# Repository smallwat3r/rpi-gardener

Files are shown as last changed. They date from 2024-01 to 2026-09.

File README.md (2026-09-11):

# RPi Gardener

Monitor your plant environment with a Raspberry Pi 4 and Raspberry Pi Pico.

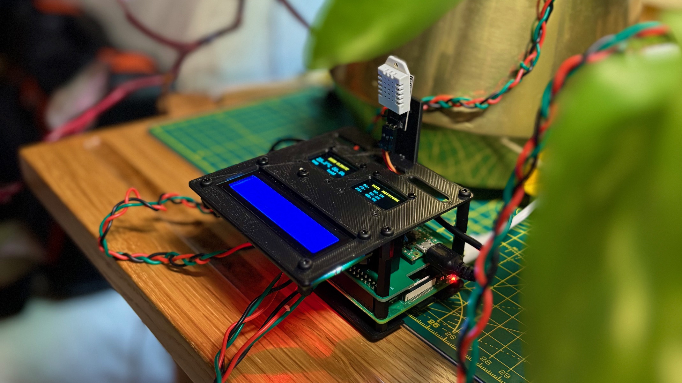
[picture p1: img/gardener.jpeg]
gardener


Tracks temperature, humidity, and soil moisture with a real-time web dashboard, displays, smart alerts, and more.

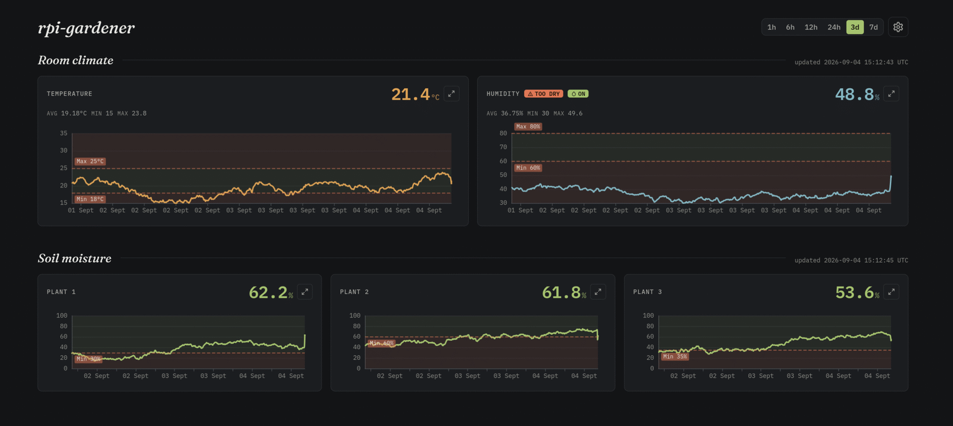
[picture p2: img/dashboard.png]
dashboard


## Features

- Real-time temperature and humidity monitoring (DHT22)
- Soil moisture tracking for up to 3 plants (Pico + capacitive sensors)
- Modern web dashboard with live charts and threshold visualization
- Visual alerts when sensor values exceed configured thresholds
- Password-protected admin interface to manage settings
- 128x64 OLED displays on both RPi and Pico
- 16x2 LCD alert display with scrolling text
- Notifications when thresholds are crossed and when alerts resolve
- Smart plug automation (TP-Link Kasa) for humidity control
- Custom RPi HAT PCB and 3D-printable case (optional, can also wire manually)
- Docker deployment

## Requirements

- Raspberry Pi 4 with Docker installed
- Raspberry Pi Pico (connected via USB for soil moisture sensors)
- DHT22 temperature/humidity sensor
- 2x SSD1306 OLED displays (128x64) - one for Pico, one optional for RPi
- 3x capacitive soil moisture sensors (v1.2)
- 1602A LCD with I2C backpack (optional, for alert display)
- TP-Link Kasa smart plug (optional, for automatic humidity control)

### Why both a Pico and a Raspberry Pi?

The Raspberry Pi 4 doesn't have analog-to-digital converter (ADC) inputs,
which are required to read capacitive soil moisture sensors. A common solution
is to add an external ADC module (like the ADS1115) to the RPi's I2C bus.
However, this project uses a Raspberry Pi Pico instead for several reasons:

- **Practical**: I already had a Pico lying around, so why not put it to use
- **More GPIO**: The Pico provides 3 ADC pins and 26 GPIO pins total, leaving
  plenty of room for additional sensors or peripherals without competing for
  the RPi's limited GPIO. Future additions like light sensors, water level
  sensors, or relay controls can be handled entirely by the Pico
- **Architectural separation**: Keeping sensor reading on a dedicated
  microcontroller isolates it from the main application. The Pico handles
  real-time ADC sampling and display updates, while the RPi focuses on the web
  server, database, and notifications. If the RPi application crashes or
  restarts, the Pico keeps running independently
- **Network scalability**: Using a Pico W instead of the standard Pico allows
  sensors to communicate over WiFi rather than USB serial. This enables a
  distributed setup where multiple Picos in different locations (greenhouse,
  garden beds, indoor plants) can all report back to a single RPi base station
  over the network

## Quick Start

### Deploy from your machine

First create a `.env` in this checkout, see [Configure Environment](#3-configure-environment)
for the values:

    cp .env.example .env

Then, with SSH access to the Pi (Raspberry Pi OS, a user with sudo), one
command provisions the host, syncs the code and starts the stack:

    make deploy DEPLOY_HOST=pi@gardener.local

`DEPLOY_HOST` is anything `ssh` accepts, `user@host`, an IP, or an alias from
your SSH config.

Provisioning is idempotent and covers: I2C, a 50MB journald cap and swap off
(both to limit SD card wear), Docker via get.docker.com, the docker group,
and the monthly Tailscale cert renewal cron. Your `.env` is copied to the Pi
on the first deploy only, later edits are made on the Pi. Re-run
`make deploy` to ship code changes.

The manual steps below are what `make deploy` does, for reference.

### 1. Prepare the Raspberry Pi

Enable I2C:

    sudo raspi-config  # Interface Options -> I2C -> Enable
    sudo modprobe i2c-dev
    echo "i2c-dev" | sudo tee -a /etc/modules

Cap the system journal so it cannot wear the SD card (container logs are
already capped in `docker-compose.yml`):

    sudo mkdir -p /etc/systemd/journald.conf.d
    printf '[Journal]\nSystemMaxUse=50M\n' | sudo tee /etc/systemd/journald.conf.d/sdcard.conf
    sudo systemctl restart systemd-journald

### 2. Install Docker

    curl -fsSL https://get.docker.com | sudo sh
    sudo usermod -aG docker $USER
    sudo reboot  # reboot pi

### 3. Configure Environment

Create a `.env` file:

```sh
# SSL certificate (use your RPi's local IP)
CERT_IP=192.168.1.100

# Admin password for the settings UI (optional, off by default)
# When set, the settings UI asks for username "admin" and this password
ADMIN_PASSWORD=your_secure_password

# DHT22 thresholds (optional, these are defaults)
MAX_TEMPERATURE=25
MIN_TEMPERATURE=18
MAX_HUMIDITY=65
MIN_HUMIDITY=40

# Moisture thresholds (optional)
# Default for all plants
MIN_MOISTURE=30
MIN_MOISTURE_PLANT_1=25
MIN_MOISTURE_PLANT_2=30
MIN_MOISTURE_PLANT_3=35

# Notifications (optional, set to 1 to enable)
ENABLE_NOTIFICATION_SERVICE=0
# Backends: "gmail", "slack", or "gmail,slack" for both
NOTIFICATION_BACKENDS=gmail

# Gmail
GMAIL_SENDER=
GMAIL_RECIPIENTS=
GMAIL_USERNAME=
GMAIL_PASSWORD=

# Slack (create webhook at https://api.slack.com/messaging/webhooks)
SLACK_WEBHOOK_URL=

# Humidifier (optional, TP-Link Kasa smart plug)
# Automatically controls a humidifier based on humidity alerts
ENABLE_HUMIDIFIER=0
HUMIDIFIER_HOST=192.168.1.100  # IP address of your Kasa plug

# OLED display (optional, SSD1306 128x64)
# Shows temperature and humidity readings
ENABLE_OLED=0

# LCD 1602A alert display (optional)
# Shows active alerts with scrolling text
ENABLE_LCD=0
LCD_I2C_ADDRESS=0x27           # Use 0x3F if 0x27 doesn't work
LCD_SCROLL_DELAY_SEC=0.7       # Scroll speed (lower = faster)
```

### 4. Start Services

    make up

The dashboard will be available at `https://YOUR-RPI-IP/`

(Accept the self-signed certificate warning in your browser)

### 5. Set Up the Pico

See [pico/README.md](./pico/README.md) for Pico installation instructions.

## Commands

### Production (Raspberry Pi)

```bash
make up          # Start all services
make up-rebuild  # Rebuild (clears static volume for fresh FE)
make down        # Stop services
make logs        # View all logs
make logs-app    # View app container logs
make restart     # Restart services
make clean       # Stop and remove volumes
make mprestart   # Restart Pico script (if it loses sync)
```

### Development (local machine)

Run the dashboard locally without RPi hardware. The dev environment uses mock
sensors (`MOCK_SENSORS=1`) to generate realistic data without physical hardware.

```bash
cp .env.example .env   # Configure environment
make dev               # Start dev environment
make dev-seed          # Seed database with sample data
make dev-logs          # View logs
make dev-down          # Stop dev environment
make dev-rebuild       # Rebuild after frontend changes
```

The dev dashboard will be available at `http://localhost:5000/`

### Testing

```bash
make devdeps     # Install dev dependencies
make test        # Run test suite
make lint        # Run linters
```

## Pico Communication

The Pico sends moisture readings via USB serial as JSON, including raw ADC values for debugging:

    {"plant-1": {"pct": 45.2, "raw": 29550}, "plant-2": {"pct": 67.8, "raw": 25000}, ...}

The RPi auto-detects `/dev/ttyACM0` or `/dev/ttyACM1` and persists readings directly to the database.

## Data Management

- Historical data is automatically deleted after the configured retention period (default: 7 days)
- Retention period can be changed via the admin interface
- Database persisted in Docker volume `rpi-gardener-db`
- Regenerate SSL certs by removing volume: `docker volume rm rpi-gardener-certs`

## Troubleshooting

See [TROUBLESHOOTING.md](./TROUBLESHOOTING.md) for common issues and solutions.

## Security

This project is designed for local home networks:
- HTTPS with self-signed certificates
- Dashboard is publicly accessible (read-only)
- Settings UI is open by default, set `ADMIN_PASSWORD` to protect it with HTTP Basic Auth
- Do not expose to the internet without additional security

## Remote access with Tailscale (optional)

To reach the dashboard from outside your home network with a trusted (non
self-signed) certificate, put the Pi on a [Tailscale](https://tailscale.com)
tailnet and let nginx serve a Tailscale-issued cert.

nginx picks the certificate by hostname (SNI): requests to your `*.ts.net`
name get the Tailscale cert, everything else (local IP, `gardener.local`)
keeps the self-signed cert. Nothing changes for users who don't use Tailscale.

Seed the cert once on the Pi host (Tailscale must be installed and up):

```sh
./docker/tailscale-cert-renew.sh
```

Tailscale certs expire after 90 days. `make deploy` schedules the script in
the root crontab to renew monthly, or add it yourself (`sudo crontab -e`):

```cron
0 4 1 * * /path/to/rpi-gardener/docker/tailscale-cert-renew.sh >> /var/log/ts-cert.log 2>&1
```

The script is a no-op if Tailscale isn't installed, so it's safe to leave
scheduled regardless. Certs live in the persistent `rpi-gardener-certs` volume,
so they survive deploys and are not regenerated on `make up`.

## Hardware Build

There are two ways to build the hardware: using a custom PCB with 3D-printed case, or manual wiring on a breadboard.

### Option 1: Custom PCB Hat + Case

A custom PCB that mounts as a Raspberry Pi HAT with an integrated Pico. Includes 3D-printable base and display plates.

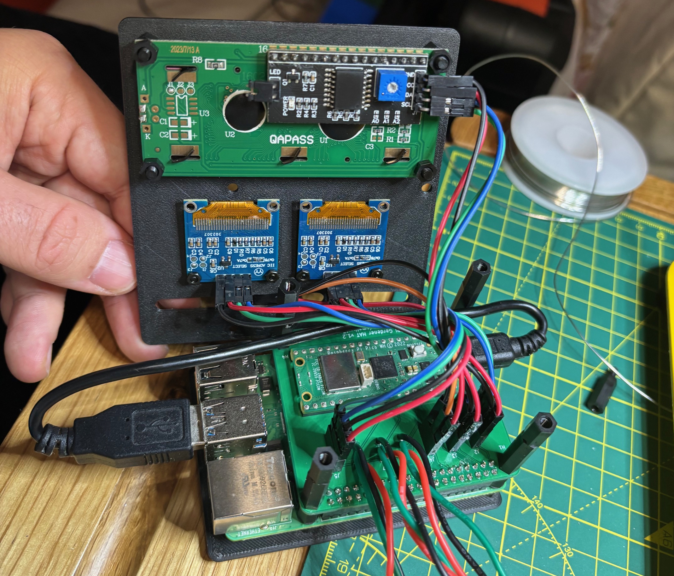
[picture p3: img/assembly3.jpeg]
pcb_with_case


See [hardware/README.md](./hardware/README.md) for:
- PCB specifications and manufacturing files
- 3D printable case files (OpenSCAD/STL)
- Complete bill of materials
- Step-by-step assembly instructions

### Option 2: Manual Wiring

For prototyping or if you prefer not to use the PCB. 

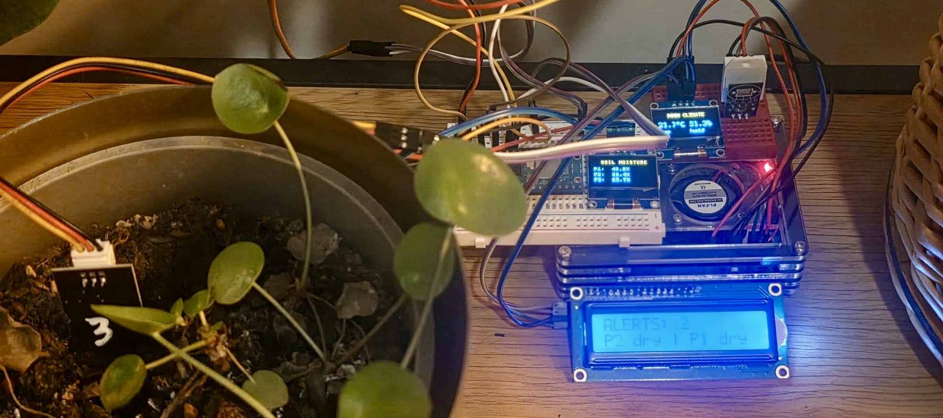
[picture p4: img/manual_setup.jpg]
manual_setup


Refer to [hardware/README.md](./hardware/README.md) for pin assignments and use the wiring diagram below as a reference.

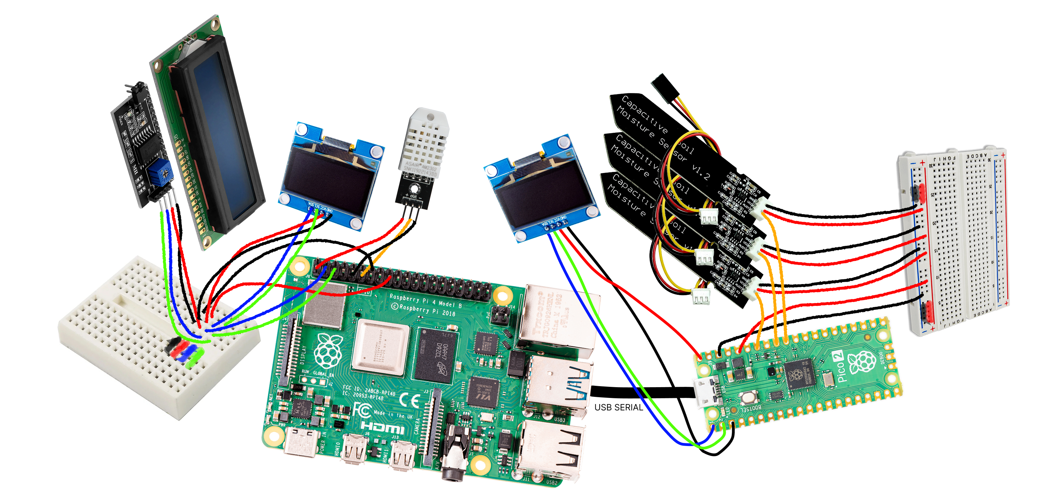
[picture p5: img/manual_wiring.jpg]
manual_wiring


## License

This project uses a dual-license structure:

- **Software** (code, scripts, configurations): [MIT License](./LICENSE)
- **Hardware** (`hardware/` directory): [CERN-OHL-P v2](./hardware/LICENSE)

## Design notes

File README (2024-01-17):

RPI DHT22 SERVER
----------------

This project contains necessarry files and scripts to read temperature and 
humidity data from a DHT22 sensor, wired to a Raspberry Pi 4. It stores the 
results every 2 seconds in a local Sqlite database, and renders them on a bare 
simple frontend using ChartJS powered by Flask and web-sockets.

REQUIREMENTS
------------

Get and build Python 3.12 from source

    sudo apt update
    sudo apt install build-essential zlib1g-dev libncurses5-dev libgdbm-dev \
        libnss3-dev libssl-dev libreadline-dev libffi-dev libsqlite3-dev
    wget https://python.org/ftp/python/3.12.1/Python-3.12.1.tgz
    tar -xf Python-3.12.1.tgz 
    cd Python-3.12.1
    ./configure --enable-optimizations
    sudo make altinstall

Create a Python virtual environment and install the Python dependencies 
(this is a one-off command)

    make venv deps
    
Install screen to run the commands in the background and keep them persistant

    sudo apt install screen

USAGE
-----

Run the dht sensor polling service
    
    make polling

From another terminal window, run the flask server
    
    make server

Run the commands in screen in order to keep them persistant over the SSH
session
   
    screen -d -m make polling
    screen -d -m make server

You can then list the running screen sessions with
   
    screen -ls

More screen commands see

    screen --help

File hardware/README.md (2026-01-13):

# RPi Gardener HAT

A custom PCB that combines a Raspberry Pi HAT with an integrated Raspberry Pi Pico for the RPi Gardener project.

## Contents

| Section | Description |
|---|---|
| [PCB](#pcb) | Board specifications, components, pinouts, manufacturing |
| [Case](#case) | 3D printable base and display plates |
| [Assembly](#assembly) | Hardware requirements, stack diagram, build steps |
| [Troubleshooting](#troubleshooting) | Common issues and solutions |

---

## PCB Hat

### Overview

This PCB serves as a unified interface board that:
- Mounts directly on a Raspberry Pi as a HAT (Hardware Attached on Top)
- Integrates a Raspberry Pi Pico for analog sensor readings
- Provides connectors for all sensors and displays

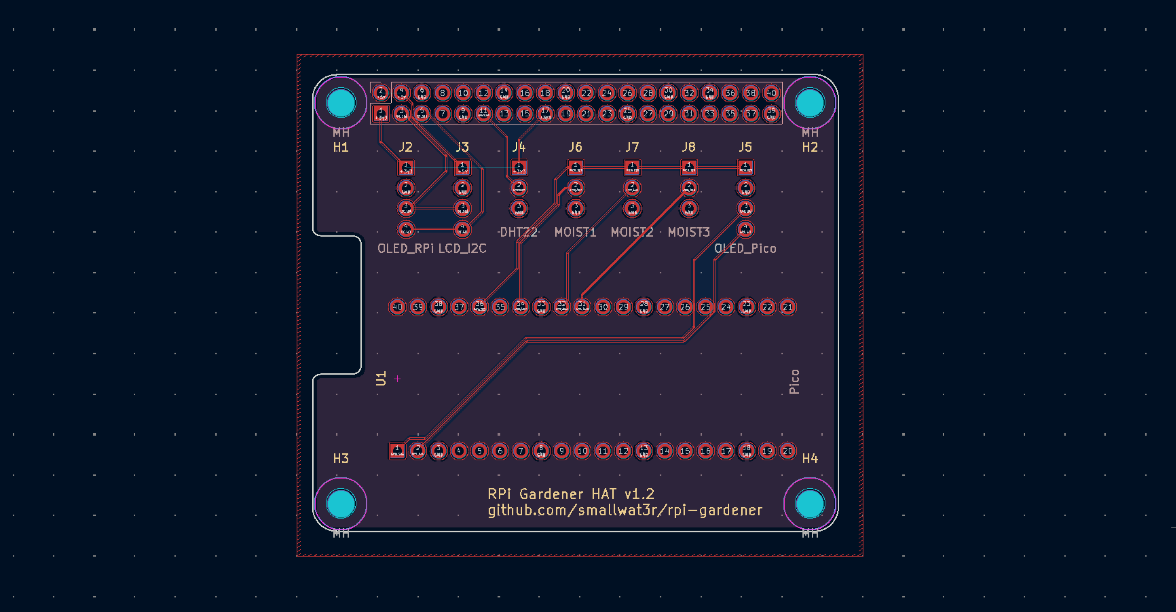
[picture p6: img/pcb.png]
pcb


### Board Specifications

| Property | Value |
|---|---|
| Dimensions | 65mm x 56mm (standard RPi HAT size) |
| Layers | 2 (F.Cu, B.Cu) |
| Thickness | 1.6mm |
| Mounting Holes | 4x M3 at standard HAT positions |
| Ground Planes | Both layers (unified GND net) |
| KiCad Version | 9.x |

### Components

#### Connectors

| Ref | Description | Pins | Connection |
|-----|---|---|---|
| J1 | RPi GPIO Header | 2x20 | Raspberry Pi 40-pin GPIO |
| J2 | OLED Display (RPi) | 1x4 | I2C SSD1306 128x64 |
| J3 | LCD Display | 1x4 | I2C 1602A with PCF8574 |
| J4 | DHT22 Sensor | 1x3 | Temperature/Humidity |
| J5 | OLED Display (Pico) | 1x4 | I2C SSD1306 128x64 |
| J6 | Moisture Sensor 1 | 1x3 | Capacitive soil sensor |
| J7 | Moisture Sensor 2 | 1x3 | Capacitive soil sensor |
| J8 | Moisture Sensor 3 | 1x3 | Capacitive soil sensor |

#### Modules

| Ref | Description | Footprint |
|-----|---|---|
| U1 | Raspberry Pi Pico | Through-hole (40 pins) |

#### Mounting

| Ref | Description |
|-----|---|
| H1-H4 | M3 mounting holes at standard HAT positions |

### Pin Assignments

#### Raspberry Pi GPIO (directly from J1)

| Function | GPIO | Pin |
|---|---|-----|
| I2C SDA | GPIO2 | 3 |
| I2C SCL | GPIO3 | 5 |
| DHT22 Data | GPIO17 | 11 |
| 3.3V Power | - | 1, 17 |
| 5V Power | - | 2, 4 |
| Ground | - | 6, 9, 14, 20, 25, 30, 34, 39 |

#### Raspberry Pi Pico (U1)

| Function | GPIO | Pin |
|---|---|-----|
| OLED SDA | GP0 | 1 |
| OLED SCL | GP1 | 2 |
| Moisture 1 | GP26/ADC0 | 31 |
| Moisture 2 | GP27/ADC1 | 32 |
| Moisture 3 | GP28/ADC2 | 34 |
| 3.3V Out | 3V3 | 36 |
| Ground | GND | 3, 8, 13, 18, 23, 28, 33, 38 |

### Connector Pinouts

#### J2 - OLED RPi (SSD1306 I2C)
```
Pin 1: VCC (3.3V)
Pin 2: GND
Pin 3: SDA (GPIO2)
Pin 4: SCL (GPIO3)
```

#### J3 - LCD I2C (1602A with PCF8574)
```
Pin 1: VCC (5V)
Pin 2: GND
Pin 3: SDA (GPIO2)
Pin 4: SCL (GPIO3)
```

#### J4 - DHT22 Sensor
```
Pin 1: VCC (3.3V)
Pin 2: DATA (GPIO17)
Pin 3: GND
```

#### J5 - OLED Pico (SSD1306 I2C)
```
Pin 1: VCC (Pico 3.3V)
Pin 2: GND
Pin 3: SDA (GP0)
Pin 4: SCL (GP1)
```

#### J6, J7, J8 - Moisture Sensors
```
Pin 1: VCC (Pico 3.3V)
Pin 2: SIG (GP26/GP27/GP28)
Pin 3: GND
```

### I2C Bus Configuration

The board has two separate I2C buses:

#### RPi I2C Bus (GPIO2/GPIO3)
- OLED Display (J2) - typically address 0x3C
- LCD Display (J3) - typically address 0x27 or 0x3F

#### Pico I2C Bus (GP0/GP1)
- OLED Display (J5) - typically address 0x3C

### USB Passthrough

The Pico's USB port is accessible at the board edge for:
- Serial communication with the Raspberry Pi
- Firmware updates
- Debugging

Connect using a USB-A to Micro-USB cable from any RPi USB port to the Pico.

### Files

| File | Description |
|---|---|
| `kicad/rpi-gardener-hat.kicad_pro` | KiCad project file |
| `kicad/rpi-gardener-hat.kicad_sch` | Schematic |
| `kicad/rpi-gardener-hat.kicad_pcb` | PCB layout |
| `kicad/rpi-gardener-hat.pretty/` | Custom footprint library |
| `kicad/gerber.zip` | Manufacturing files (Gerber + drill) |

### Manufacturing

Upload `kicad/gerber.zip` to your preferred PCB manufacturer (JLCPCB, PCBWay, etc.).

Recommended settings:
- Layers: 2
- Thickness: 1.6mm
- Surface finish: HASL (lead free) or ENIG
- Copper weight: 1oz
- Solder mask: Any color
- Silkscreen: White

Design rules used:
- Min track width: 0.2mm
- Min clearance: 0.2mm
- Min via diameter: 0.6mm
- Min via drill: 0.3mm

---

## Case

3D printable base and display plates for mounting the full assembly.

### Files

| File | Description |
|---|---|
| `case/rpi-gardener-base.scad` | OpenSCAD source for base plate |
| `case/rpi-gardener-base.stl` | Base plate STL |
| `case/rpi-gardener-display-plate.scad` | OpenSCAD source for display plate |
| `case/rpi-gardener-display-plate.stl` | Display plate STL |

### Base Plate

| Property | Value |
|---|---|
| Dimensions | 90mm x 62mm x 1.5mm |
| Mounting Pattern | 58mm x 49.5mm (matches RPi/HAT) |
| Hole Diameter | 3.2mm (M3 clearance) |
| Features | Ventilation slots, USB cable cutout |

### Display Plate

| Property | Value |
|---|---|
| Dimensions | 90mm x 100mm x 1.5mm |
| OLED Cutouts | 2x 26mm x 15mm (for 0.96" SSD1306) |
| OLED Mount Spacing | 23mm x 23.5mm (M2) |
| LCD Cutout | 73mm x 25mm (for 1602A) |
| LCD Mount Spacing | 75mm x 31mm (M3) |
| Features | Cable routing slots, DHT22 holder tab |

### Printing Settings

- Layer height: 0.2mm
- Infill: 20%
- Material: PLA or PETG
- Supports: Not required

### Regenerating STL

```bash
cd case
openscad -o rpi-gardener-base.stl rpi-gardener-base.scad
openscad -o rpi-gardener-display-plate.stl rpi-gardener-display-plate.scad
```

### Customization

Edit the `.scad` files to adjust dimensions, enable/disable features, or change OLED type (0.96" vs 1.3").

---

## Assembly

### Required Hardware

#### Stack Hardware

| Item | Quantity | Notes |
|---|---|---|
| M3 screws | 4 | Bottom, thread into F-M spacers |
| M3 screws | 4 | Top, thread into F-F spacers |
| M3 spacers (5-6mm, F-M) | 4 | Between base and RPi |
| M3 washers (1mm) | 4 | Between RPi and next spacer |
| M3 spacers (10mm, F-M) | 4 | Between RPi and HAT |
| M3 spacers (20mm, F-M) | 4 | Above HAT |
| M3 spacers (5-6mm, F-F) | 4 | Top, screws thread into these |
| Rubber bumpons (8-10mm) | 4 | Anti-slip feet under base plate |

#### Display Mounting

| Item | Quantity | Notes |
|---|---|---|
| M2 screws (1mm) | 8 | To attach OLEDs to display plate |
| M2 nuts | 8 | To secure OLEDs |
| M3 screws | 4 | To attach LCD to display plate |
| M3 spacers (5-6mm, F-M) | 4 | Between display plate and LCD |
| M3 nuts | 4 | To secure LCD |
| M3 screw | 1 | Front, to mount DHT22 to display plate pole |
| M3 spacer (F-M) | 1 | Between DHT22 and display plate pole |
| M3 nut | 1 | Back, to secure DHT22 |

#### PCB Components

| Item | Quantity | Notes |
|---|---|---|
| 2x16 pin male-to-female header | 2 | For J1 (RPi GPIO), allows RPi plug/unplug |
| 1x4 pin male-to-female header | 3 | For J2, J5 (OLEDs) and J3 (LCD) |
| 1x3 pin male-to-female header | 1 | For J4 (DHT22) |
| Pin headers for Pico | 2x20 | Or solder Pico directly |
| Capacitive soil sensors | 3 | Solder directly to J6, J7, J8 |
| Small dupont wires (M-F) | - | Modules have male pins, HAT has female headers |

**Note:** The RPi 4 has native M2.5 mounting holes. You may need to lightly drill or ream them to fit M3 screws.

### Stack Diagram

```
    ┌─────────────────────┐
    │   4x M3 screws      │  ← Thread into F-F spacers
    ├─────────────────────┤
    │   Display plate     │  ← Top plate with OLEDs + LCD
    ├─────────────────────┤
    │   4x spacers 5-6mm  │  ← F-F (top screws thread here)
    │ + 4x spacers 20mm   │  ← F-M
    ├─────────────────────┤
    │   HAT (PCB)         │  ← RPi Gardener HAT with Pico
    ├─────────────────────┤
    │   4x spacers 10mm   │  ← F-M
    ├─────────────────────┤
    │   4x washers 1mm    │  ← Fine adjustment
    ├─────────────────────┤
    │   Raspberry Pi      │  ← RPi 4
    ├─────────────────────┤
    │   4x spacers 5-6mm  │  ← F-M
    ├─────────────────────┤
    │   Base plate        │  ← 3D printed base
    ├─────────────────────┤
    │   4x M3 screws      │  ← Thread into F-M spacers
    └─────────────────────┘
```

### Assembly Steps

1. **Solder Components to HAT**
   - Solder 2x 16-pin male-to-female headers for J1 (RPi GPIO)
   - Solder 1x4 pin male-to-female headers for J2, J5 (OLEDs) and J3 (LCD)
   - Solder 1x3 pin male-to-female header for J4 (DHT22)
   - Solder capacitive soil sensors directly to J6, J7, J8 (see note below)
   - Mount Pico: solder directly or use pin headers

   **Note on soil sensor wiring:** From testing, soldering the sensors directly to the PCB produces much more reliable readings than joining multiple dupont cables, which can introduce noise and intermittent connections. An even better alternative is to use JST-XH connectors on both ends for a secure, detachable connection. You'll likely need long cables to reach plants around the installation.

2. **Mount Displays to Plate**
   - Attach OLEDs using 8x M2 screws (1mm) and 8x M2 nuts
   - Attach LCD using 4x M3 screws, 4x M3 spacers (5-6mm F-M), and 4x M3 nuts

3. **Build the Stack**
   - Insert 4x M3 screws from bottom through base plate into 4x 5-6mm F-M spacers
   - Place Raspberry Pi onto spacers
   - Add 4x 1mm washers
   - Add 4x 10mm F-M spacers
   - Mount HAT, seating GPIO connector onto RPi header
   - Add 4x 20mm F-M spacers
   - Add 4x 5-6mm F-F spacers

4. **Connect Peripherals**
   - Connect OLED displays to J2, J5 using dupont wires
   - Connect LCD 1602A to J3 using dupont wires
   - Connect DHT22 to J4 using dupont wires
   - Connect Pico USB to RPi USB port

5. **Secure Top Plate**
   - Place display plate on top
   - Secure with 4x M3 screws from top

6. **Mount DHT22 Sensor**
   - Attach DHT22 to display plate pole using M3 screw (front), M3 spacer F-M, and M3 nut (back)

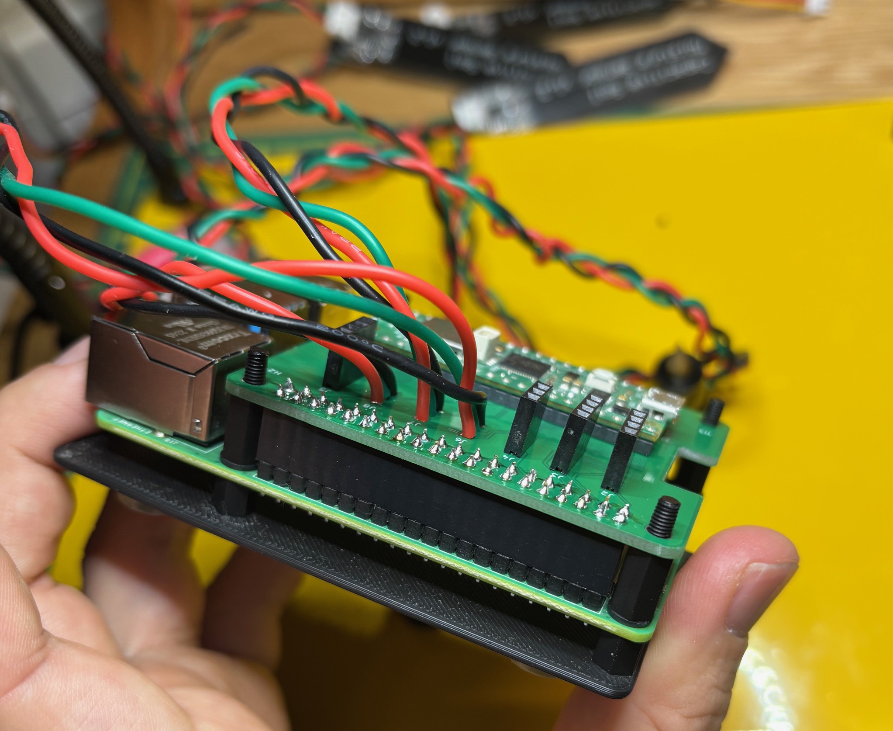
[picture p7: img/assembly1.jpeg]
assembly1

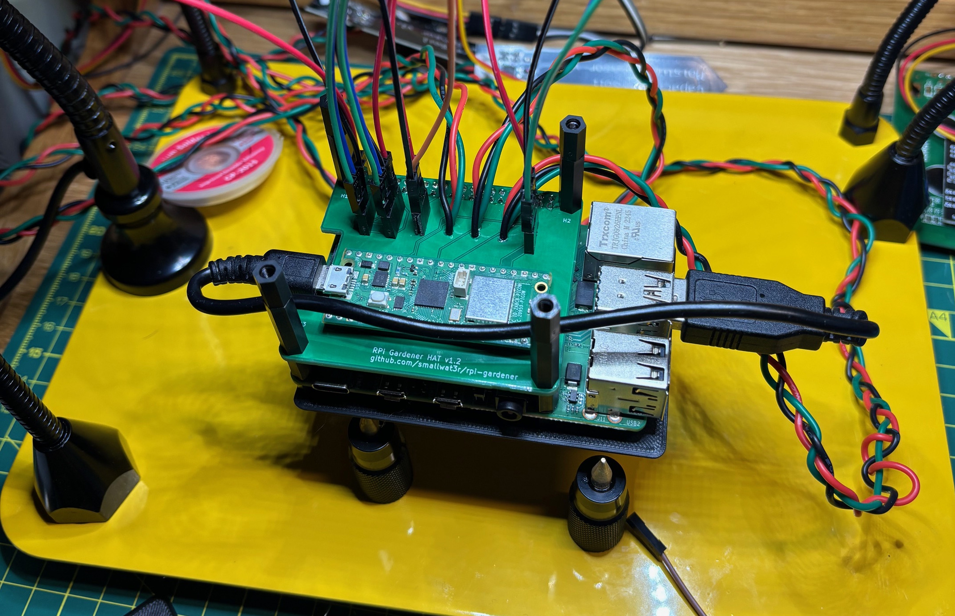
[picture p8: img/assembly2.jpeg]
assembly2

assembly3

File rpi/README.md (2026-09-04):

# RPi

Python code for the Raspberry Pi 4.

## Architecture

Services communicate via Redis pub/sub:

```
DHT Polling ──┐                  ┌── Web Server (SSE)
              │                  ├── Notification Service (Gmail/Slack)
              ├── Redis ─────────┼── Humidifier Service (Kasa smart plug)
Pico Reader ──┘                  ├── OLED Service (SSD1306 display)
                                 └── LCD Service (1602A alert display)
```

## Services

### DHT22 Polling Service (`dht/`)

Reads temperature and humidity from the DHT22 sensor every 2 seconds and
publishes every reading to the event bus. Only every 5th reading is stored,
batched into one database commit per minute, to limit SD card wear
(`PollingSettings.persist_every` and `flush_interval_sec`).

    make polling

### Pico Serial Reader (`pico/`)

Reads soil moisture data from a Pico microcontroller via USB serial.
Parses JSON lines and publishes readings to the event bus.

    make pico

### Web Server (`server/`)

REST API and SSE server for the dashboard. Uses Starlette (ASGI).
Subscribes to the event bus for real-time updates.

    make serve       # Development (with hot reload)
    make serve-prod  # Production (Unix socket for Nginx)

### Notification Service (`notifications/`)

Subscribes to alert events and sends notifications via Gmail/Slack.
Runs independently of the web server.

    python -m rpi.notifications

### Humidifier Service (`humidifier/`)

Controls a humidifier via TP-Link Kasa smart plug based on humidity alerts.
Turns on when humidity drops below the threshold,
and turns off when humidity recovers.

    python -m rpi.humidifier

### OLED Service (`oled/`)

Displays temperature and humidity readings on an SSD1306 OLED display (128x64).
Subscribes to DHT reading events and renders the latest values.

    python -m rpi.oled

Example display:
```
  ROOM CLIMATE
22.5°C    55.0%
temp      humid
```

### LCD Service (`lcd/`)

Displays active alerts on a 16x2 character LCD (1602A with I2C backpack).
Shows "All OK" when no alerts are active, or scrolling alert text when
thresholds are exceeded.

    python -m rpi.lcd

Example display:
```
ALERTS: 3
P1 dry | Temp low | Humid high
       ^^^^^^^^^^^^^^^^^^^^^^^^ (scrolling)
```

## Endpoints

| Endpoint | Method | Description |
|---|---|---|
| `/health` | GET | Service health check |
| `/api/dashboard` | GET | Dashboard data (JSON) |
| `/api/thresholds` | GET | Configured alert thresholds (JSON) |
| `/api/admin/settings` | GET | Admin settings (requires auth) |
| `/api/admin/settings` | PUT | Update admin settings (requires auth) |
| `/sse/dht/latest` | SSE | Real-time DHT22 readings |
| `/sse/pico/latest` | SSE | Real-time Pico readings |
| `/sse/humidifier/state` | SSE | Real-time humidifier state |

## Dashboard Features

The web dashboard displays:

- **Room Climate**: Temperature and humidity charts with min/max threshold lines
- **Soil Moisture**: Per-plant moisture charts with minimum threshold lines
- **Visual Alerts**: Warning badges appear when values exceed thresholds
  - Temperature: "Too hot" / "Too cold"
  - Humidity: "Too humid" / "Too dry"
  - Moisture: "Thirsty"
- **Danger Zones**: Red-shaded areas on charts indicate out-of-range values

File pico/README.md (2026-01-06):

# Pico

This module uses MicroPython and needs to be set up on the Raspberry Pico
board, to read values from capacitive soil moisture sensors (v1.2).

## Features

- Reads moisture levels from up to 3 capacitive soil sensors
- Sends readings to the RPi via USB serial (no WiFi required)
- Displays readings on an SSD1306 OLED display (128x64)

### OLED Display

The Pico shows soil moisture readings on a 128x64 SSD1306 OLED display
connected via I2C (GPIO 0/1). The display is optional - if not connected,
readings are still sent via USB serial.

Example display:
```
  SOIL MOISTURE
P1:  45.2%
P2:  67.8%
P3:  52.1%
```

## Installation

Connect the Pico to the RPi via USB cable.

From the RPi, install the MicroPython tooling:

    make mpdeps

### First-time setup

1. Install MicroPython on the Pico if not already done:
   - Hold BOOTSEL button while plugging in USB
   - Download the `.uf2` file from https://micropython.org/download/RPI_PICO/
   - Copy it to the mounted drive

2. Install the `ssd1306` display library:

       uv run mpremote mip install ssd1306

3. Copy `main.py` to the Pico:

       uv run mpremote cp pico/main.py :main.py

4. Restart the Pico to start the script:

       uv run mpremote soft-reset

5. Verify it's working (should see JSON output every 2 seconds):

       cat /dev/ttyACM0

   Example output (includes raw ADC values for debugging):

       {"plant-1": {"pct": 45.2, "raw": 29550}, "plant-2": {"pct": 67.8, "raw": 25000}, "plant-3": {"pct": 52.1, "raw": 28000}}

The script auto-runs on boot, so unplugging and replugging the Pico will
restart it automatically.

## Configuration

The following constants can be adjusted in `main.py`:

| Constant | Default | Description |
|---|---|---|
| `POLLING_INTERVAL_SEC` | 2 | Seconds between sensor readings |

Plant calibration values may need adjustment based on your sensors:

```python
plants = (
    Plant("plant-1", ADC(Pin(26)), Calibration(15600, 43500)),
    Plant("plant-2", ADC(Pin(27)), Calibration(15600, 43500)),
    Plant("plant-3", ADC(Pin(28)), Calibration(14500, 44000)),
)
```

## Useful Commands

Edit a file directly on the Pico:

    make mpedit file=<file>

Restart the main script on the Pico:

    make mprestart

## Troubleshooting

**Pico stops sending data**: The Pico can sometimes lose sync. A cron job
on the RPi can restart it periodically:

    0 */3 * * * (cd /home/pi/rpi-gardener && make mprestart)

**Incorrect moisture readings**: Calibration values vary by sensor.
Submerge sensor in water (100%) and dry air (0%) to determine min/max.

**Serial port not found**: Ensure the Pico is connected via USB. The app
auto-detects `/dev/ttyACM0` or `/dev/ttyACM1`. Check available ports:

    ls /dev/ttyACM*

**mpremote can't connect (raw repl error)**: The Pico is busy running code.
Unplug and replug the USB cable, then quickly run `mpremote` before `main.py`
starts.

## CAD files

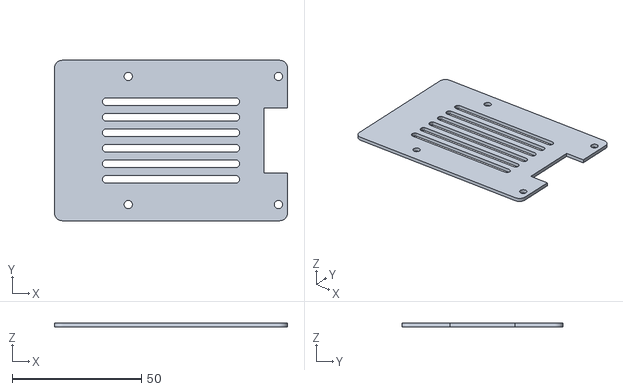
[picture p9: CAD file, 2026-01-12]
hardware/case/rpi-gardener-base.stl
90.0 x 62.0 x 1.50

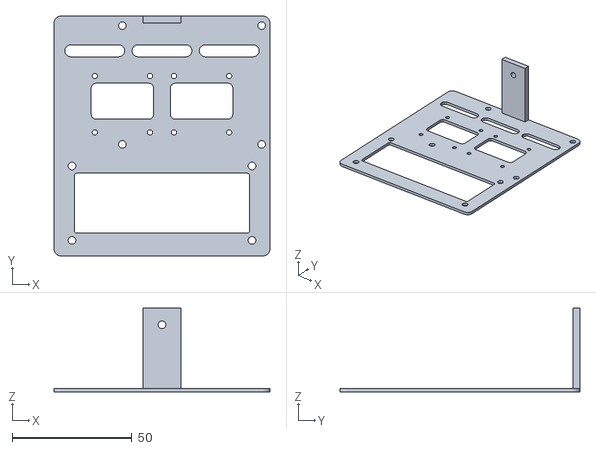
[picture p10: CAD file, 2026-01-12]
hardware/case/rpi-gardener-display-plate.stl
90.0 x 100.0 x 35.0

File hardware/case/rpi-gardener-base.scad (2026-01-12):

// RPi Gardener HAT Base
// Flat base with M3 holes for RPi 4 and HAT mounting with spacers
// Export to STL: OpenSCAD -> File -> Export -> STL

/* [Base Dimensions] */
// Base sized to support full Raspberry Pi 4 (85mm x 56mm)
base_width = 90;          // mm - slightly larger than Pi for margin
base_depth = 62;          // mm - slightly larger than Pi for margin
base_thickness = 1.5;     // mm
corner_radius = 3;        // mm

/* [Mounting Holes] */
// Standard RPi 4 mounting pattern: 58mm x 49.5mm
// Holes are 3.5mm from board edges on the Pi
// Same holes work for both RPi and HAT (they align)
hole_spacing_x = 58;      // mm between holes horizontally
hole_spacing_y = 49.5;    // mm between holes vertically
hole_diameter = 3.2;      // mm - M3 clearance hole
// Match PCB hole positions from the right edge
hole_offset_x = base_width - hole_spacing_x - 3.5;  // mm from left (3.5mm from right edge)
hole_offset_y = (base_depth - hole_spacing_y) / 2;  // centered vertically

/* [Ventilation] */
vent_slots = true;        // Add ventilation slots
vent_width = 3;           // mm
vent_length = 50;         // mm - longer to match wider base
vent_count = 6;           // more slots for better cooling

/* [Cable Cutout] */
usb_cutout = true;        // Cutout for USB/power cables
usb_cutout_width = 25;    // mm
usb_cutout_depth = 10;    // mm

// Modules
module rounded_rect(w, d, h, r) {
    hull() {
        translate([r, r, 0]) cylinder(h=h, r=r, $fn=32);
        translate([w-r, r, 0]) cylinder(h=h, r=r, $fn=32);
        translate([r, d-r, 0]) cylinder(h=h, r=r, $fn=32);
        translate([w-r, d-r, 0]) cylinder(h=h, r=r, $fn=32);
    }
}

module vent_slot(length, width) {
    hull() {
        translate([0, 0, 0]) cylinder(h=base_thickness+0.2, d=width, $fn=16);
        translate([length, 0, 0]) cylinder(h=base_thickness+0.2, d=width, $fn=16);
    }
}

// Main assembly
module base() {
    difference() {
        // Base plate
        rounded_rect(base_width, base_depth, base_thickness, corner_radius);

        // Mounting holes (M3) - same positions for RPi and HAT
        // Hole 1 (H1 position)
        translate([hole_offset_x, hole_offset_y, -0.1])
            cylinder(h=base_thickness+0.2, d=hole_diameter, $fn=32);

        // Hole 2 (H2 position)
        translate([hole_offset_x + hole_spacing_x, hole_offset_y, -0.1])
            cylinder(h=base_thickness+0.2, d=hole_diameter, $fn=32);

        // Hole 3 (H3 position)
        translate([hole_offset_x, hole_offset_y + hole_spacing_y, -0.1])
            cylinder(h=base_thickness+0.2, d=hole_diameter, $fn=32);

        // Hole 4 (H4 position)
        translate([hole_offset_x + hole_spacing_x, hole_offset_y + hole_spacing_y, -0.1])
            cylinder(h=base_thickness+0.2, d=hole_diameter, $fn=32);

        // Ventilation slots
        if (vent_slots) {
            slot_start_x = (base_width - vent_length) / 2;
            slot_spacing = (base_depth - 20) / (vent_count + 1);
            for (i = [1:vent_count]) {
                translate([slot_start_x, 10 + i * slot_spacing, -0.1])
                    vent_slot(vent_length, vent_width);
            }
        }

        // USB/Power cable cutout
        if (usb_cutout) {
            translate([base_width - usb_cutout_depth + 1, (base_depth - usb_cutout_width) / 2, -0.1])
                cube([usb_cutout_depth + 1, usb_cutout_width, base_thickness + 0.2]);
        }
    }
}

// Render the base
base();

// Info
echo("=== RPi Gardener HAT Base ===");
echo(str("Base size: ", base_width, "mm x ", base_depth, "mm x ", base_thickness, "mm"));
echo(str("Supports: Raspberry Pi 4 (85mm x 56mm)"));
echo(str("Hole pattern: ", hole_spacing_x, "mm x ", hole_spacing_y, "mm (matches PCB)"));
echo(str("Hole positions: (", hole_offset_x, ",", hole_offset_y, ") to (", hole_offset_x+hole_spacing_x, ",", hole_offset_y+hole_spacing_y, ")"));
echo(str("Hole diameter: ", hole_diameter, "mm (M3 clearance)"));
echo("");
echo("Assembly with spacers:");
echo("1. Insert M3 screws from bottom through base holes");
echo("2. Add spacer (e.g. 5-6mm) for RPi clearance");
echo("3. Mount Raspberry Pi 4 (center on base)");
echo("4. Add spacer (e.g. 10-12mm) for HAT clearance");
echo("5. Mount HAT");
echo("6. Secure with M3 nuts on top");

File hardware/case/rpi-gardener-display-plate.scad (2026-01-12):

// RPi Gardener Display Plate
// Top plate for mounting OLED screens and LCD 1602A above the HAT
// Export to STL: OpenSCAD -> File -> Export -> STL

/* [Base Dimensions] */
// Extended depth to accommodate LCD 1602A below OLEDs
base_width = 90;          // mm
base_depth = 100;         // mm - sized to fit LCD 1602A below OLEDs
base_thickness = 1.5;     // mm
corner_radius = 3;        // mm

/* [Mounting Holes - RPi/HAT Pattern] */
// Standard RPi 4 mounting pattern: 58mm x 49.5mm
// Positioned toward the top of the extended plate
hole_spacing_x = 58;      // mm between holes horizontally
hole_spacing_y = 49.5;    // mm between holes vertically
hole_diameter = 3.2;      // mm - M3 clearance hole
// Match PCB hole positions from the right edge
hole_offset_x = base_width - hole_spacing_x - 3.5;  // mm from left (3.5mm from right edge)
hole_offset_y = base_depth - hole_spacing_y - 4;    // near top (4mm from top edge, avoids OLED/cable slots)

/* [OLED Display Configuration] */
// Number of OLED displays: 1 = single centered, 2 = dual side by side
oled_count = 2;

// OLED type: 0 = Custom, 1 = 0.96" OLED (SSD1306), 2 = 1.3" OLED
oled_type = 1;

// Gap between OLED displays when using dual mode (mm)
oled_gap = 6;

// OLED vertical position from top edge (mm)
oled_offset_from_top = 22;

/* [LCD 1602A Configuration] */
// Enable LCD 1602A mounting
lcd_1602_enabled = true;

// LCD 1602A dimensions (standard module ~80x36mm, screen with bezel ~72x24mm)
lcd_1602_cutout = [73, 25];           // Display window (with 1mm margin)
lcd_1602_mount_spacing = [75, 31];    // Mounting hole spacing
lcd_1602_module_size = [80, 36];      // Full module size

// LCD vertical position from bottom edge (mm)
lcd_offset_from_bottom = 4;


/* [Cable Routing Slots] */
// Slots at the top for sensor cables (DHT22, moisture sensors, etc.)
cable_slots_enabled = true;
cable_slot_count = 3;         // Number of slots
cable_slot_width = 20;        // mm - width of each slot
cable_slot_height = 5;        // mm - height of each slot
cable_slot_spacing = 8;       // mm - gap between slots
cable_slot_from_top = 12;     // mm - positioned between mounting holes and OLEDs

/* [DHT22 Holder Configuration] */
// Vertical tab mount for DHT22 sensor module (screw-mounted)
dht22_holder_enabled = true;
dht22_tab_width = 16;         // mm - width of the tab
dht22_tab_height = 35;        // mm - height of tab above plate
dht22_tab_thickness = 3;      // mm - thickness of the tab
dht22_hole_diameter = 3.2;    // mm - M3 clearance hole for screw
dht22_hole_height = 28;       // mm - height of hole center from plate surface


/* [Custom OLED Cutout] */
// Only used when oled_type = 0
custom_cutout_width = 30;   // mm
custom_cutout_height = 15;  // mm

/* [Display Module Mounting] */
display_mount_holes = true;
oled_mount_hole_diameter = 2.2;   // mm - M2 clearance for OLEDs
lcd_mount_hole_diameter = 3.2;    // mm - M3 clearance for 1602A

// OLED presets
oled_096_cutout = [26, 15];
oled_096_mount_spacing = [23, 23.5];
oled_096_mount_y_offset = -1.25;    // mm - bottom holes 5mm from cutout, top holes 2.5mm from cutout
oled_096_module_size = [27, 27];

oled_13_cutout = [32, 18];
oled_13_mount_spacing = [29, 27];
oled_13_mount_y_offset = 0;
oled_13_module_size = [35, 33];

// Get OLED dimensions based on type
function get_oled_cutout() =
    oled_type == 1 ? oled_096_cutout :
    oled_type == 2 ? oled_13_cutout :
    [custom_cutout_width, custom_cutout_height];

function get_oled_mount_spacing() =
    oled_type == 1 ? oled_096_mount_spacing :
    oled_type == 2 ? oled_13_mount_spacing :
    [custom_cutout_width + 6, custom_cutout_height + 6];

function get_oled_mount_y_offset() =
    oled_type == 1 ? oled_096_mount_y_offset :
    oled_type == 2 ? oled_13_mount_y_offset :
    0;

function get_oled_module_size() =
    oled_type == 1 ? oled_096_module_size :
    oled_type == 2 ? oled_13_module_size :
    [custom_cutout_width + 6, custom_cutout_height + 6];

// Modules
module rounded_rect(w, d, h, r) {
    hull() {
        translate([r, r, 0]) cylinder(h=h, r=r, $fn=32);
        translate([w-r, r, 0]) cylinder(h=h, r=r, $fn=32);
        translate([r, d-r, 0]) cylinder(h=h, r=r, $fn=32);
        translate([w-r, d-r, 0]) cylinder(h=h, r=r, $fn=32);
    }
}

module rounded_cutout(w, h, thickness, r=2) {
    hull() {
        translate([r, r, 0]) cylinder(h=thickness, r=r, $fn=16);
        translate([w-r, r, 0]) cylinder(h=thickness, r=r, $fn=16);
        translate([r, h-r, 0]) cylinder(h=thickness, r=r, $fn=16);
        translate([w-r, h-r, 0]) cylinder(h=thickness, r=r, $fn=16);
    }
}

// OLED display cutout and mounting holes
module oled_cutout_and_mount(center_x, center_y, cutout, mount_spacing, mount_y_offset=0) {
    // Display cutout
    translate([center_x - cutout[0]/2, center_y - cutout[1]/2, -0.1])
        rounded_cutout(cutout[0], cutout[1], base_thickness + 0.2);

    // Mounting holes (M2)
    if (display_mount_holes) {
        for (dx = [-1, 1]) {
            for (dy = [-1, 1]) {
                translate([
                    center_x + dx * mount_spacing[0] / 2,
                    center_y + dy * mount_spacing[1] / 2 + mount_y_offset,
                    -0.1
                ])
                cylinder(h=base_thickness+0.2, d=oled_mount_hole_diameter, $fn=32);
            }
        }
    }
}

// Cable routing slot
module cable_slot(width, height) {
    hull() {
        translate([0, 0, 0]) cylinder(h=base_thickness+0.2, d=height, $fn=16);
        translate([width, 0, 0]) cylinder(h=base_thickness+0.2, d=height, $fn=16);
    }
}

// DHT22 vertical tab mount with screw hole
// Flat tab extends from top edge, hole on the vertical face
module dht22_holder() {
    tab_x = base_width / 2 - dht22_tab_width / 2;

    difference() {
        // Vertical tab
        translate([tab_x, base_depth - dht22_tab_thickness, 0])
            cube([dht22_tab_width, dht22_tab_thickness, dht22_tab_height]);

        // Screw hole through the face (horizontal, pointing outward)
        translate([base_width / 2, base_depth + 0.1, dht22_hole_height])
            rotate([90, 0, 0])
            cylinder(h=dht22_tab_thickness + 0.2, d=dht22_hole_diameter, $fn=24);
    }
}


// LCD 1602A cutout and mounting holes
module lcd_1602_cutout_and_mount(center_x, center_y) {
    // Display window cutout
    translate([center_x - lcd_1602_cutout[0]/2, center_y - lcd_1602_cutout[1]/2, -0.1])
        rounded_cutout(lcd_1602_cutout[0], lcd_1602_cutout[1], base_thickness + 0.2, r=1);

    // Mounting holes (M3) at corners
    if (display_mount_holes) {
        for (dx = [-1, 1]) {
            for (dy = [-1, 1]) {
                translate([
                    center_x + dx * lcd_1602_mount_spacing[0] / 2,
                    center_y + dy * lcd_1602_mount_spacing[1] / 2,
                    -0.1
                ])
                cylinder(h=base_thickness+0.2, d=lcd_mount_hole_diameter, $fn=32);
            }
        }
    }
}


// Main assembly - flat display plate
module display_plate() {
    oled_cutout = get_oled_cutout();
    oled_mount_spacing = get_oled_mount_spacing();
    oled_mount_y_offset = get_oled_mount_y_offset();
    oled_module_size = get_oled_module_size();
    center_x = base_width / 2;
    oled_center_y = base_depth - oled_offset_from_top - oled_module_size[1] / 2;
    lcd_center_y = lcd_offset_from_bottom + lcd_1602_module_size[1] / 2;
    oled_dual_offset = (oled_module_size[0] + oled_gap) / 2;

    difference() {
        // Flat plate with rounded corners
        rounded_rect(base_width, base_depth, base_thickness, corner_radius);

        // RPi/HAT mounting holes (M3)
        translate([hole_offset_x, hole_offset_y, -0.1])
            cylinder(h=base_thickness+0.2, d=hole_diameter, $fn=32);
        translate([hole_offset_x + hole_spacing_x, hole_offset_y, -0.1])
            cylinder(h=base_thickness+0.2, d=hole_diameter, $fn=32);
        translate([hole_offset_x, hole_offset_y + hole_spacing_y, -0.1])
            cylinder(h=base_thickness+0.2, d=hole_diameter, $fn=32);
        translate([hole_offset_x + hole_spacing_x, hole_offset_y + hole_spacing_y, -0.1])
            cylinder(h=base_thickness+0.2, d=hole_diameter, $fn=32);

        // OLED cutouts and mounting holes
        if (oled_count == 1) {
            oled_cutout_and_mount(center_x, oled_center_y, oled_cutout, oled_mount_spacing, oled_mount_y_offset);
        } else {
            oled_cutout_and_mount(center_x - oled_dual_offset, oled_center_y, oled_cutout, oled_mount_spacing, oled_mount_y_offset);
            oled_cutout_and_mount(center_x + oled_dual_offset, oled_center_y, oled_cutout, oled_mount_spacing, oled_mount_y_offset);
        }

        // LCD 1602A cutout and mounting holes
        if (lcd_1602_enabled) {
            lcd_1602_cutout_and_mount(center_x, lcd_center_y);
        }
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

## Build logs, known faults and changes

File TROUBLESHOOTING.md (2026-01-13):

# Troubleshooting

## Software

**Pico stops sending data**: The Pico can lose sync. Add a cron job to
restart it periodically:

    0 */3 * * * (cd /home/pi/rpi-gardener && make mprestart)

**Email notifications not working**: Ensure `GMAIL_PASSWORD` uses a
Gmail App Password (not your account password).

**Container won't start**: Check that I2C is enabled and devices exist:

    ls -la /dev/i2c-* /dev/gpiochip0 /dev/gpiomem /dev/ttyACM*

**Pico on different serial port**: The app auto-detects `/dev/ttyACM0` or
`/dev/ttyACM1`. You can also set `PICO_SERIAL_PORT` in `.env` to specify
a custom port.

## Hardware

**I2C devices not detected**:
- Check address conflicts (OLED typically 0x3C, LCD typically 0x27)
- Verify correct voltage (OLED: 3.3V, LCD: 5V)
- Use `i2cdetect -y 1` on RPi to scan bus

**Moisture sensors not reading**:
- Verify Pico is powered (check 3V3 LED)
- Check USB serial connection to RPi
- Ensure sensors are connected to correct ADC pins

**DHT22 not responding**:
- Verify 3.3V power
- Check GPIO17 connection
- Some DHT22 modules need a pull-up resistor (4.7kΩ)

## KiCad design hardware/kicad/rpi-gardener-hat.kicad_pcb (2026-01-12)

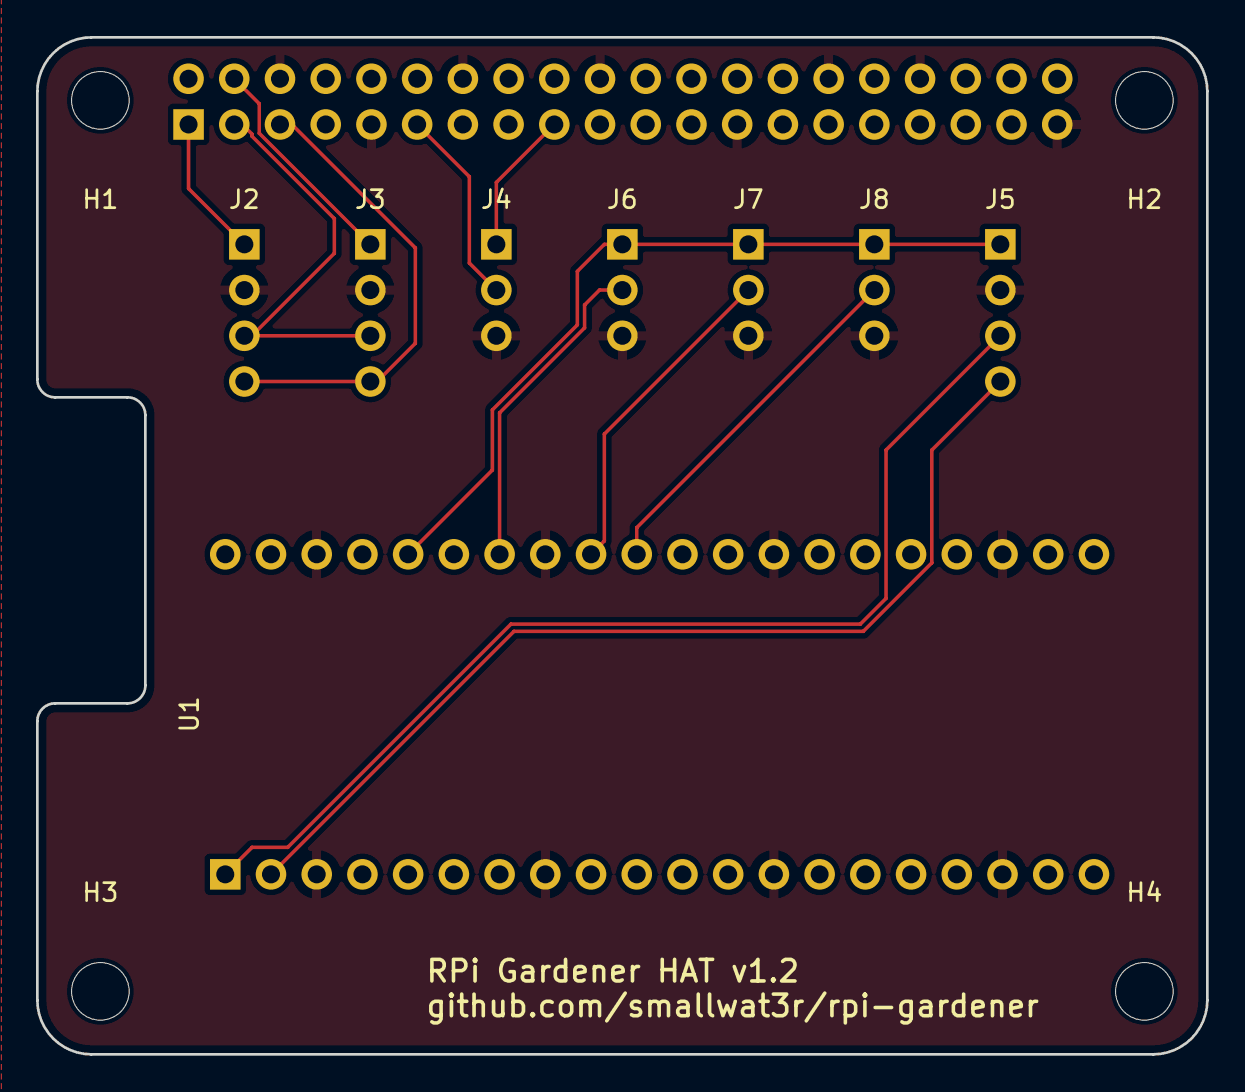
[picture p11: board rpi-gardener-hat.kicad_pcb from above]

Board: 2 copper layers, 65.0 x 56.5 mm, 13 parts (1 on the bottom side), 12 nets.

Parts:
H1, H2, H3, H4: MH; MountingHole_3.2mm_M3
J1: RPi_GPIO; PinSocket_2x20_P2.54mm_Vertical
J2: OLED_RPi; PinHeader_1x04_P2.54mm_Vertical
J3: LCD_I2C; PinHeader_1x04_P2.54mm_Vertical
J4: DHT22; PinHeader_1x03_P2.54mm_Vertical
J5: OLED_Pico; PinHeader_1x04_P2.54mm_Vertical
J6: MOIST1; PinHeader_1x03_P2.54mm_Vertical
J7: MOIST2; PinHeader_1x03_P2.54mm_Vertical
J8: MOIST3; PinHeader_1x03_P2.54mm_Vertical
U1: Pico; RPi_Pico_SMD_TH

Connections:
+3V3: J1.1 (3V3), J1.17 (3V3), J2.1 (VCC), J4.1 (VCC)
+5V: J1.2 (5V), J1.4 (5V), J3.1 (VCC)
GND: J1.6 (GND), J1.9 (GND), J1.14 (GND), J1.20 (GND), J1.25 (GND), J1.30 (GND), J1.34 (GND), J1.39 (GND), J2.2 (GND), J3.2 (GND), J4.3 (GND), J5.2 (GND), J6.3 (GND), J7.3 (GND), J8.3 (GND), U1.3 (GND), U1.8 (GND), U1.13 (GND), U1.18 (GND), U1.23 (GND), U1.28 (GND), U1.33 (AGND), U1.38 (GND)
GP0_SDA: J5.3 (SDA), U1.1 (GP0)
GP1_SCL: J5.4 (SCL), U1.2 (GP1)
GP26_ADC0: J8.2 (SIG), U1.31 (GP26/ADC0)
GP27_ADC1: J7.2 (SIG), U1.32 (GP27/ADC1)
GP28_ADC2: J6.2 (SIG), U1.34 (GP28/ADC2)
GPIO17_DHT: J1.11 (GPIO17), J4.2 (DATA)
I2C_SCL: J1.5 (GPIO3/SCL1), J2.4 (SCL), J3.4 (SCL)
I2C_SDA: J1.3 (GPIO2/SDA1), J2.3 (SDA), J3.3 (SDA)
PICO_3V3: J5.1 (VCC), J6.1 (VCC), J7.1 (VCC), J8.1 (VCC), U1.36 (3V3_OUT)

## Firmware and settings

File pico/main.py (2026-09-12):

# This module uses Micropython and needs to be set-up on the Raspberry Pico
# board, to read values from capacitive soil moisture sensors (v1.2).
import gc
import json
import time

from machine import ADC, I2C, WDT, Pin
from ssd1306 import SSD1306_I2C

# Configuration
POLLING_INTERVAL_SEC = 2
# Samples averaged per reading, the capacitive probes and the RP2040 ADC are
# both noisy on a single conversion
ADC_SAMPLES = 16

# Display configuration
DISPLAY_WIDTH = 128
DISPLAY_HEIGHT = 64
DISPLAY_I2C_FREQ = 200000
# Yellow zone: 0-15, Blue zone: 16-63
DISPLAY_HEADER_Y = 4
DISPLAY_VALUES_START_Y = 20
DISPLAY_VALUES_LINE_HEIGHT = 14


class Plant:
    def __init__(self, name, adc_pin, calibration):
        self.name = name
        self.pin = adc_pin
        self.cal = calibration

    @property
    def id(self):
        return self.name.split("-")[-1]


class Calibration:
    def __init__(self, cmin, cmax):
        self.min = cmin
        self.max = cmax

    @property
    def diff(self):
        return self.max - self.min


# After some testing, it seems calibration changes from device to device,
# so I've calibrated them independently to ensure we get the most sensible
# readings.
plants = (
    Plant("plant-1", ADC(Pin(26)), Calibration(15600, 43500)),
    Plant("plant-2", ADC(Pin(27)), Calibration(15600, 43500)),
    Plant("plant-3", ADC(Pin(28)), Calibration(14500, 44000)),
)


class Display(SSD1306_I2C):
    def clear(self):
        self.fill(0)

    def render(self, readings):
        """Render readings with yellow header and blue values."""
        self.clear()
        # Yellow zone: Header
        self.text("SOIL MOISTURE", 16, DISPLAY_HEADER_Y)
        # Blue zone: Plant readings
        y_pos = DISPLAY_VALUES_START_Y
        for plant in plants:
            pct = readings[plant.name]["pct"]
            self.text(f"P{plant.id}: {pct:5.1f}%", 0, y_pos)
            y_pos += DISPLAY_VALUES_LINE_HEIGHT
        self.show()


def read_moisture(plant):
    """Read moisture level from a plant sensor, clamped to 0-100%."""
    raw = sum(plant.pin.read_u16() for _ in range(ADC_SAMPLES)) // ADC_SAMPLES
    pct = round((plant.cal.max - raw) * 100 / plant.cal.diff, 1)
    return {"pct": max(0, min(100, pct)), "raw": raw}


def init_display():
    """Initialize display, return None if not available."""
    try:
        i2c = I2C(0, scl=Pin(1), sda=Pin(0), freq=DISPLAY_I2C_FREQ)
        return Display(DISPLAY_WIDTH, DISPLAY_HEIGHT, i2c)
    except OSError:
        return None


def update_display(display, readings):
    """Update display with current readings."""
    if display is None:
        return
    try:
        display.render(readings)
    except OSError:
        pass


def main():
    """Main loop for reading sensors and sending data via USB serial."""
    # Watchdog first, so a hung I2C bus during display init still resets
    wdt = WDT(timeout=8000)
    display = init_display()
    readings = {plant.name: {"pct": 0, "raw": 0} for plant in plants}

    while True:
        for plant in plants:
            readings[plant.name] = read_moisture(plant)

        update_display(display, readings)

        # Send JSON over USB serial (stdout)
        print(json.dumps(readings))

        time.sleep(POLLING_INTERVAL_SEC)
        gc.collect()
        wdt.feed()


main()

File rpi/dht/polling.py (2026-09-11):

"""Poll DHT22 sensor for new data, and persist results in SQLite.

Initializes the database on first run. Default polling frequency is 2 seconds
(configurable via PollingSettings). The DHT22 sensor updates every 2 seconds,
so polling faster would return cached results.
"""

import asyncio
from datetime import UTC, datetime
from typing import Protocol, override

from rpi.dht.audit import audit_reading
from rpi.dht.models import Measure, Reading
from rpi.lib.alerts import AlertTracker, Namespace, create_alert_publisher
from rpi.lib.config import DHT22_BOUNDS, MeasureName, Unit
from rpi.lib.db import close_db, get_db, init_db
from rpi.lib.eventbus import DHTReadingEvent, EventPublisher
from rpi.lib.polling import PollingService
from rpi.logging import configure, get_logger

logger = get_logger("dht.polling")


class DHTSensor(Protocol):
    """Protocol for DHT sensor interface."""

    @property
    def temperature(self) -> float: ...
    @property
    def humidity(self) -> float: ...
    def exit(self) -> None: ...


class DHTPollingService(PollingService[Reading]):
    """Polling service for the DHT22 temperature/humidity sensor."""

    def __init__(
        self,
        sensor: DHTSensor,
        publisher: EventPublisher,
        alert_tracker: AlertTracker,
    ) -> None:
        super().__init__(name="DHT22")
        self._dht = sensor
        self._publisher = publisher
        self._alert_tracker = alert_tracker

    @override
    async def initialize(self) -> None:
        """Initialize database and register alert callback."""
        await init_db()
        await self._publisher.connect()
        self._alert_tracker.register_callback(
            Namespace.DHT, create_alert_publisher(self._publisher)
        )

    @override
    async def cleanup(self) -> None:
        """Clean up DHT22 sensor, event publisher, and database."""
        self._dht.exit()
        await self._publisher.close()
        await close_db()

    @override
    async def poll(self) -> Reading | None:
        """Poll the DHT22 sensor for new reading values."""
        # Run sync sensor reads in thread pool
        temperature = await asyncio.to_thread(lambda: self._dht.temperature)
        humidity = await asyncio.to_thread(lambda: self._dht.humidity)

        reading = Reading(
            Measure(temperature, Unit.CELSIUS),
            Measure(humidity, Unit.PERCENT),
            datetime.now(UTC),
        )
        logger.debug("Read %s, %s", reading.temperature, reading.humidity)
        return reading

    @override
    async def audit(self, reading: Reading) -> bool:
        """Audit the reading against thresholds and DHT22 bounds."""
        # Check DHT22 bounds
        for name in MeasureName:
            measure = getattr(reading, name).value
            bmin, bmax = DHT22_BOUNDS[name]
            if measure < bmin or measure > bmax:
                logger.error(
                    "%s reading outside bounds of DHT22 sensor: %s",
                    name.capitalize(),
                    measure,
                )
                return False

        # Check thresholds and potentially trigger notifications
        await audit_reading(reading, self._alert_tracker)
        return True

    @override
    async def persist(self, readings: list[Reading]) -> None:
        """Persist a batch of readings into the database in one transaction."""
        async with get_db() as db:
            await db.executemany(
                "INSERT INTO reading (temperature, humidity, recording_time) VALUES (?, ?, ?)",
                [
                    (
                        r.temperature.value,
                        r.humidity.value,
                        int(r.recording_time.timestamp()),
                    )
                    for r in readings
                ],
            )
        logger.debug("Persisted %d readings", len(readings))

    @override
    async def publish(self, reading: Reading) -> None:
        """Publish the reading to the event bus for real-time SSE updates."""
        event = DHTReadingEvent(
            temperature=reading.temperature.value,
            humidity=reading.humidity.value,
            recording_time=reading.recording_time,
        )
        await self._publisher.publish(event)

    @override
    def on_poll_error(self, error: Exception) -> None:
        """Handle DHT22-specific errors."""
        if isinstance(error, RuntimeError):
            # DHT library raises RuntimeError for transient sensor issues
            # (e.g., checksum failures, timing issues). Log and retry.
            logger.debug("DHT22 sensor read error: %s", error)
        else:
            super().on_poll_error(error)


def _create_sensor() -> DHTSensor:
    """Create sensor based on configuration."""
    from rpi.lib.config import get_settings

    if get_settings().mock_sensors:
        from rpi.lib.mock import MockDHTSensor

        logger.info("Using mock DHT sensor")
        return MockDHTSensor()
    from adafruit_dht import DHT22
    from board import D17

    return DHT22(D17)  # type: ignore[no-any-return]


def main() -> None:
    """Main entry point for the polling service."""
    configure()
    sensor = _create_sensor()
    publisher = EventPublisher()
    alert_tracker = AlertTracker()
    service = DHTPollingService(sensor, publisher, alert_tracker)
    service.run()


if __name__ == "__main__":
    main()

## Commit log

2024-01-16 Better framework to work with raw SQL
2024-01-24 Dead simple filtering for period
2024-01-26 Fix stats endpoint for websocket
    [server.py]
2024-01-31 Add Pico integration
2024-01-31 Manage around display failures
    [main.py]
2024-01-31 Add pico graph
2024-02-03 Webhooks for pico
2024-02-04 Calibration for each sensors
2025-04-06 Add wiring schema
2025-12-23 Switch to deterministic cleanup
2025-12-24 Add wiring tables
2025-12-25 Ability to mock sensors for development
2025-12-25 Use Redis based broker
    [service.py]
2025-12-26 Use buckets for faster queries
2026-01-02 Add pico sync script
2026-01-02 Auto detect Pico port
2026-01-05 Update wiring
2026-01-06 Update wiring diagram with new LCD
2026-01-12 PCB (#13)
    * PCB
    * WIP
    * Updated
    * Fix
    * Add gerber file
    * Fix
    * Mounts for displays
    * Fixes
    * Clean up
    * Fix
    * Ensure LCD bezel fit
    * Holder for DHT
    * Fixes
    * Update README
    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
    [rpi-gardener-base.scad, rpi-gardener-base.stl, rpi-gardener-display-plate.scad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]
2026-01-13 Add missing assembly step for DHT22
2026-01-26 Use SSE instead of websockets (#14)
    * Use SSE instead of websockets
    * Updates
    * Fix for mock sensors
    * Fix mock sensors
    * Remove logs
    [logging.py, polling.py]
2026-03-07 Update directory name
    [rpi-gardener-base.scad, rpi-gardener-base.stl, rpi-gardener-display-plate.scad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]
2026-08-23 Validate admin threshold updates against stored settings
    Min/max consistency was only checked when both bounds arrived in the
    same request, so a partial update could persist min >= max (e.g.
    setting only max below the stored min), after which both alerts fire
    and never resolve. Merge request values over the currently effective
    settings and validate the result before writing.
2026-08-23 Harden health endpoint: hide error details, detect stale sensors
    The unauthenticated /health response echoed raw exception strings from
    database and Redis failures (paths, connection details). Log the detail
    and return a generic status instead.
    Sensor checks claimed to verify recent data but passed on any row ever
    written, so a dead polling service kept /health green. Compare the
    latest reading's epoch against a 5 minute staleness window.
2026-08-23 Bound Redis publisher socket timeouts
    EventPublisher uses the sync Redis client from within async polling
    loops, so a Redis outage during publish or reconnect could stall the
    event loop indefinitely. Cap connect and socket operations at 5
    seconds. A full switch to the async client would cascade through the
    sync alert callback interface, not worth it at a 2 second poll
    interval.
2026-08-23 Remove unused alert count cache and ThresholdChecker protocol
    is_any_alert() had no callers, so the _AlertCountCache maintained for
    its O(1) lookup was pure overhead for a system tracking at most a
    handful of sensors. ThresholdChecker was a protocol with a single
    implementation, audit_reading now takes AlertTracker directly. Cuts
    ~90 lines with no behaviour change.
2026-09-11 Make the event bus and alert pipeline fully async
    EventPublisher moves from a sync redis client to redis.asyncio so
    publishing no longer blocks the event loop. AlertCallback becomes
    async, which drops AlertTracker's asyncio.Lock (one task per tracker
    now) along with its unused reset()/reset_matching()/get_lock()
    machinery. CompositeNotifier.send() no longer collects/raises
    PartialNotificationError, since each notifier already retries and
    logs internally, so NotificationError/PartialNotificationError become
    dead code and are removed from exceptions.py.
    PollingService.publish() becomes async, and frequency_sec handling
    now checks "is None" instead of falsy, so PicoPollingService can pass
    freq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
    [polling.py, service.py]
2026-09-11 Compute dashboard stats client side, drop dht_stats.sql
    /api/dashboard no longer runs a separate SQL stats query; queries.py
    gains get_dashboard_data() returning bucketed chart data plus latest
    readings, with a bucket_sec field. The frontend derives min/avg/max
    from the already-fetched chart data (computeStats in useDashboard.ts)
    and merges live SSE readings bucket-aware (mergeLive) instead of a
    naive prepend+filter, so stats stay live with SSE updates without a
    second query.
2026-09-11 Fix dev proxy to match actual SSE routes
    The /pico and /dht proxy entries pointed at routes that no longer
    exist, the backend serves everything under /sse/*. Proxy /sse instead.
2026-09-11 Drop privileged flag from rpi compose service
    GPIO/i2c access is already granted via explicit group_add gids, so
    the container doesn't need full privileged mode.
2026-09-11 Fix logging.configure() to allow level changes across calls
    It was wrapped in @lru_cache(maxsize=1), so a second call (e.g. from
    tests, or with a different level) silently kept the first level and
    skipped reattaching. Now it always sets the level and only skips
    re-adding the handler if one is already attached.
    [logging.py]
2026-09-11 Unmask systempaths so GPIO works unprivileged
    Dropping the privileged flag masked /sys/firmware, which hides
    /proc/device-tree and stops Blinka and RPi.GPIO recognising the Pi.
    Unmasking systempaths is all that privileged mode was needed for.
2026-09-11 Round dashboard stats to 1 decimal place
    Matches the precision the DHT sensor actually provides.
2026-09-11 Add font-size-md token, tighten card/modal heading sizes
    Card and modal headings were sized the same as the dashboard title.
    Introduces a size between base and lg for them, and drops the
    letter-spacing tweaks that no longer suit the smaller size.
2026-09-12 Improve pico sensor reading and firmware robustness
    Oversample ADC readings (16x) to smooth noisy capacitive probe values
    and round moisture to 1 decimal place. Init the watchdog before the
    display so a hung I2C bus during init still triggers a reset. Drop
    the redundant Display.__init__ override and use json/time instead of
    the deprecated ujson/utime aliases.
    [main.py]
2026-09-12 Format dashboard metrics to 1 decimal place
    Apply toFixed(1) to temperature, humidity, moisture and stat values
    for consistent display. Show time-only in the "updated" label with a
    dateTime attribute for accessibility.
